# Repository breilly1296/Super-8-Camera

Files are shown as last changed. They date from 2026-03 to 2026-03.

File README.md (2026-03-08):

# Super 8 Camera

**An open-source, self-repairable Super 8 film camera.**

A fully parametric motion picture camera designed from scratch in CadQuery. Every dimension traces back to a single spec file. Every part is manufacturable. 7 field-swappable modules. 10 FDM-printable replacement parts. A complete repair manual generated from the design itself.

## Key Specifications

| Parameter | Value |
|---|---|
| Film format | Kodak Super 8 (5.79 x 4.01 mm frame) |
| Lens mount | C-mount (25.4 mm, 32 TPI, 17.526 mm FFD) |
| Frame rates | 18 fps, 24 fps (switch-selectable) |
| Shutter | 180-degree rotary disc |
| Body envelope | 135 x 80 x 48 mm |
| Body material | Aluminum 6061-T6, 2.5 mm wall |
| Film gate | Brass C360 (free-machining) |
| Drivetrain | Mabuchi FF-130SH, 2-stage Delrin spur gears (6:1) |
| Power | 4x AA alkaline (6.0 V nominal) |
| Weight | ~691 g with batteries |
| BOM cost | $722 (qty 1) / $345 (qty 100) |

## Module Architecture

The camera is organized into 7 field-swappable modules. Each module can be removed and replaced independently without disassembling the rest of the camera.

| Module | Name | Interface | Swap Level | Swap Time | Printable Parts |
|---|---|---|---|---|---|
| MOD-100 | Film Transport | Thumbscrew | Technician | 2 min | Film Channel |
| MOD-200 | Shutter | Thumbscrew | Technician | 90 s | — |
| MOD-300 | Drivetrain | Thumbscrew | Technician | 3 min | Motor Mount, Gearbox Housing, Gears |
| MOD-400 | Cartridge Bay | Snap-fit | User | 30 s | Cartridge Door |
| MOD-500 | Electronics | JST | Technician | 60 s | PCB Bracket |
| MOD-600 | Power | Snap-fit | User | 15 s | Battery Door |
| MOD-700 | Optics | Dovetail | User | 20 s | Viewfinder |

Modules interconnect via 7 JST connectors (XH 2.5 mm + VH 3.96 mm) with unique pin counts to prevent cross-connection. Each connector is keyed to exactly one module pair.

## Framework for Film

This camera borrows its philosophy from [Framework laptops](https://frame.work): **every single part is replaceable, individually purchasable, and forward-compatible across versions.**

### Every Part is Replaceable

There are no glued, riveted, or permanently bonded assemblies. Every component — from the brass film gate to the battery door hinge pin — can be removed with standard hex keys and replaced with an identical spare. The complete [spare parts catalog](super8cam/business/store_catalog.py) lists 35+ SKUs available individually, from a $3 registration pin to complete pre-assembled modules.

### Interface Specification (Frozen)

The [interface standard](super8cam/specs/interface_standard.py) defines the immutable contract between all modules and the chassis:

| Interface | Spec | Status |
|---|---|---|
| Dovetail rail | 60 deg, 4mm top / 6mm base / 3mm deep | FROZEN v1.0 |
| Thumb screws | M3, 20mm center-to-center spacing | FROZEN v1.0 |
| Module slots | 7 slots with exact X/Y/Z coordinates | FROZEN v1.0 |
| Connectors | J1-J7 pinouts, families, wire colors | FROZEN v1.0 |
| Fasteners | M2 / M2.5 / M3 / 1/4"-20 only | FROZEN v1.0 |

A MOD-100 Film Transport manufactured in 2026 will drop into a MOD-100 slot on a chassis built in 2030. The interface spec version guarantees it.

### Future-Proof: Expansion Slot

The chassis includes a reserved expansion slot (MOD-EXP) with a 10-pin JST-XH connector providing:

```
SDA, SCL, TX, RX, PWM1, PWM2, 3V3, 5V, GND, GND
```

V1 ships with a blank cover plate. This enables community-designed expansion modules:
- Digital frame counter
- Bluetooth sync / remote trigger
- Intervalometer (time-lapse)
- Sound recording module
- GPS location logger
- External light meter interface

The expansion slot position, connector pinout, and dovetail mounting are part of the frozen interface standard.

### Module Map

```
  LEFT HALF (chassis)                    RIGHT HALF
  ┌──────────────────────────────┐┌──────────────────────┐
  │  MOD-700   MOD-200           ││  MOD-400             │
  │  Optics    Shutter           ││  Cartridge Bay       │
  │  ┌─────┐  ┌──────┐          ││  ┌──────────────┐    │
  │  │Lens │  │Disc  │          ││  │Receiver      │    │
  │  │Mount│  │Shaft │  MOD-300 ││  │Door          │    │
  │  └─────┘  └──────┘  Drive   ││  └──────────────┘    │
  │                     ┌─────┐ ││                       │
  │  MOD-100            │Motor│ ││  MOD-EXP              │
  │  Film Transport     │Gears│ ││  (Expansion)          │
  │  ┌──────────────┐   └─────┘ ││  ┌───────────┐       │
  │  │Gate+Claw+Cam │           ││  │ 10-pin XH │       │
  │  │Plate+Channel │  MOD-500  ││  │ blank cap │       │
  │  └──────────────┘  ┌──────┐ ││  └───────────┘       │
  │                    │PCB   │ ││                       │
  │                    │J1-J7 │ ││                       │
  │                    └──────┘ ││                       │
  ├─────────────────────────────┤├──────────────────────-┤
  │           MOD-600  Power (Battery Bay)               │
  └──────────────────────────────┘──────────────────────-┘
```

## Design Philosophy

**Specs-driven.** `master_specs.py` defines every dimension, tolerance, material property, and derived constant. Change a wall thickness or gear ratio in one place and the entire camera regenerates to match.

**Manufacturable.** Parts are designed for real processes: 3-axis CNC aluminum, wire EDM for the claw, CNC brass for the film gate, injection-moldable Delrin gears. GD&T callouts follow ASME Y14.5.

**Validated.** The build pipeline runs timing validation, interference detection, thermal analysis, and kinematic simulation. Problems surface at build time, not on the machine shop floor.

**Self-repairable.** Every part has a replacement procedure, tools list, and cost estimate. The generated repair guide PDF walks through symptom diagnosis, module swap, and reassembly verification.

## Interactive Web Explorer

A local web application for browsing the camera design — 3D model viewers, build guide, repair manual, and parts store.

### Quick Start

```bash
cd webapp
npm install
npm run dev
```

Opens at [http://localhost:3000](http://localhost:3000). Features:

- **Home** — Full 3D assembly viewer, key stats, module overview
- **Modules** — 7 field-swappable modules with interactive 3D part viewers
- **Build Guide** — Step-by-step assembly with 3D viewer that updates at each step
- **Repair Guide** — Symptom-based diagnosis with highlighted 3D part views
- **Specs** — All specifications, cam timing diagram, validation results
- **Store** — Complete spare parts catalog (35+ SKUs)
- **About** — Framework for Film philosophy, interface standard, expansion slot docs

To regenerate data from the Python package (optional):

```bash
python webapp/generate_data.py
```

## Build Instructions

### Prerequisites

- Python 3.10+ (3.12 recommended for CadQuery compatibility)
- [Miniforge3](https://github.com/conda-forge/miniforge) (recommended for CadQuery)

### Setup

```bash
# Create conda environment with CadQuery and dependencies
conda create -n super8 python=3.12 cadquery numpy scipy matplotlib reportlab -c conda-forge -y
conda activate super8

# Install the package
cd Super-8-Camera
pip install -e .
```

### Run the Build

```bash
python -m super8cam.build
```

This executes the 7-phase pipeline:

1. **Specifications** — Prints master specs from `master_specs.py`
2. **Validation** — Timing rules, tolerance stack-ups, bearing fits
3. **Analysis** — Kinematics, motor speed check, thermal
4. **Parts Export** — Builds and exports all 27 parts (STEP + STL)
5. **Assemblies Export** — Builds and exports 8 assemblies (STEP)
6. **Interference Detection** — Boolean intersection check on critical pairs
7. **Manufacturing Outputs** — BOM, drawings, checklist, wiring diagram, repair guide

All output goes to `export/`. On Windows, set `PYTHONIOENCODING=utf-8` before running.

### Other Build Modes

```bash
python -m super8cam.build --specs          # print specs summary only
python -m super8cam.build --parts-only     # export parts only
python -m super8cam.build --analysis-only  # run analysis only
python -m super8cam.build --report-only    # generate build report only
```

## Directory Structure

```
Super-8-Camera/
  super8cam/                    Python package
    specs/
      master_specs.py           Single source of truth
      modularity.py             Module architecture + connector map + part catalog
      interface_standard.py     FROZEN interface spec (dovetails, slots, pinouts)
    parts/                      23 CadQuery part modules
    assemblies/                 8 sub-assembly modules
      full_camera.py            Master assembly + interference detection
    analysis/                   Engineering validation
      timing_validation.py      Shutter/claw timing check
      tolerance_stackup.py      Flange distance, registration, bearing fits
      kinematics.py             Claw profiles, motor speed, mechanism validation
      thermal.py                Motor heat, film zone temperature
    manufacturing/              Production outputs
      generate_bom.py           BOM with cost rollup (CSV + PDF)
      generate_drawings.py      Engineering drawing PDFs
      generate_checklist.py     Production checklist PDF
      generate_wiring.py        Wiring harness diagram PDF
      repair_guide.py           Repair & maintenance guide PDF
      generate_qr.py            QR codes + compatibility labels for all parts
    business/                   Store and catalog
      store_catalog.py          Shopify-compatible spare parts catalog (35+ SKUs)
    firmware/                   STM32L031K6 bare-metal firmware
      platformio.ini            PlatformIO build config
      src/
        main.c                  Superloop + HSI16 clock + SysTick
        motor_control.c/h       PID speed control via TIM2 PWM
        metering.c/h            Light meter + galvanometer
        encoder.c/h             Optical encoder input capture
        state_machine.c/h       IDLE/RUN/RAMPDOWN/FAULT state machine
        config.h                Tuning constants
        pinmap.h                Complete pin allocation + connector cross-ref
    build.py                    Master build orchestrator
  export/                       Generated outputs (after build)
  pyproject.toml                Package metadata + dependencies
  verify_fixes.py               25-point mechanical verification suite
```

## Generated Documents

After a full build, the `export/` directory contains:

| File | Description |
|---|---|
| `repair_guide.pdf` | Multi-page repair manual with symptom diagnosis, procedures, and spare parts order form |
| `wiring_diagram.pdf` | Wire harness diagram with connector table and cut list |
| `bom.csv` / `bom.pdf` | Bill of materials with cost rollup at qty 1/25/100 |
| `production_checklist.pdf` | 111-item manufacturing QC checklist |
| `drawings/*.pdf` | Engineering drawings for critical parts |
| `build_report.txt` | Full build report with all analysis results |
| `*.step` / `*.stl` | Part and assembly CAD files |

## Firmware

The camera firmware targets the **STM32L031K6** (ARM Cortex-M0+, 32 KB flash, 8 KB RAM) using bare-metal CMSIS. An Arduino Nano prototype target is also provided.

```bash
cd super8cam/firmware
pip install platformio
pio run -e super8_stm32l0        # build for STM32
pio run -e super8_nano           # build for Arduino Nano
pio run -e super8_stm32l0 -t upload  # flash via ST-Link
```

See `super8cam/firmware/` for the complete firmware source.

## References

- **Kodak Super 8 Film**: Frame size 5.79 x 4.01 mm, perforation pitch 4.234 mm
- **C-Mount Standard**: 25.4 mm diameter, 32 TPI thread, 17.526 mm flange focal distance
- **ASME Y14.5-2018**: Dimensioning and Tolerancing standard
- **ISO 286-1**: System of limits and fits

## License

This project is licensed under the **CERN Open Hardware Licence Version 2 — Strongly Reciprocal (CERN-OHL-S v2)**.

You may redistribute and modify this project and its documentation under the terms of the CERN-OHL-S v2. This licence requires that derivative works are distributed under the same licence terms, ensuring the hardware remains open.

See [https://ohwr.org/cern_ohl_s_v2.txt](https://ohwr.org/cern_ohl_s_v2.txt) for the full licence text.

## Contributing

Contributions are welcome. Please:

1. Fork the repository and create a feature branch
2. Ensure `python verify_fixes.py` passes all 25 checks
3. Run `python -m super8cam.build --specs` to verify imports
4. Submit a pull request with a clear description of your changes

All mechanical dimensions must come from `master_specs.py`. No magic numbers in part files.

## Acknowledgments

- [CadQuery](https://cadquery.readthedocs.io/) — Parametric CAD scripting
- [Kodak](https://www.kodak.com/en/motion/page/super-8-702) — Super 8 film format
- [PlatformIO](https://platformio.org/) — Embedded firmware toolchain
- [ReportLab](https://www.reportlab.com/) — PDF generation

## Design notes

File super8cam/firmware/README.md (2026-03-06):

# Super 8 Camera Firmware

Bare-register CMSIS firmware for the STM32L031K6 controlling all camera
subsystems: motor drive, metering, and operator interface.

## Architecture

```
main.c
 ├── clock_init()       HSI16 at 16 MHz
 ├── systick_init()     1 ms global tick (g_tick_ms)
 ├── uart_init()        USART2 115200 baud debug output
 ├── motor_init()       TIM2 PWM + encoder (TIM21 IC)
 ├── meter_init()       ADC + TIM22 galvo PWM + LEDs
 ├── state_machine_init()
 └── superloop:
      ├── state_machine_update()
      ├── debug_print()         every 500 ms
      └── __WFI()               low-power sleep
```

### Module Dependency

```
config.h  pinmap.h          (constants, no code)
    ↓         ↓
encoder.c/.h                (TIM21 input capture, 4-sample avg)
    ↓
motor_control.c/.h          (TIM2 PWM, PID, ramp, stall)
    ↓
metering.c/.h               (ADC, EV calc, galvo, LEDs)
    ↓
state_machine.c/.h          (8-state FSM, battery, cartridge)
    ↓
main.c                      (init, superloop, UART debug)
```

### State Machine

```
POWER_ON → IDLE → STARTING → RUNNING → STOPPING → IDLE
                                │
                                ├→ STALL → IDLE
                                ├→ CARTRIDGE_EMPTY → IDLE
                                └→ LOW_BATTERY → IDLE
```

| State | Motor | Metering | Entry Condition |
|---|---|---|---|
| POWER_ON | off | off | Boot / reset |
| IDLE | off | preview  | Default state |
| STARTING | ramp-up | active | Trigger pressed |
| RUNNING | PID | active | First encoder pulse |
| STOPPING | ramp-dn | active | Trigger released |
| STALL | killed  | active | No encoder pulse within 200 ms |
| CARTRIDGE_EMPTY | killed  | active | 5 consecutive missed frames |
| LOW_BATTERY | killed  | active | Vbat < 4200 mV |

## Pin Map

| Pin  | Mode | Function |
|---|---|---|
| PA0  | AF2  | TIM2_CH1 — Motor PWM output |
| PA1  | IN | FPS select switch (low=18, high=24) |
| PA2  | IN | Trigger button (active low) |
| PA3  | OUT  | Fault/warning LED |
| PA4  | AF4  | TIM22_CH1 — Galvanometer needle PWM |
| PA5  | OUT  | Green LED (exposure OK) |
| PA6  | OUT  | Red LED (underexposed) |
| PA7  | ANA  | ADC_IN7 — Photodiode / TIA |
| PA9  | AF4  | USART2_TX — Debug UART |
| PA10 | AF4  | USART2_RX — Debug UART |
| PA13 | AF0  | SWDIO (reserved) |
| PA14 | AF0  | SWCLK (reserved) |
| PB0  | IN | DIP bit 0 (ASA select) |
| PB1  | IN | DIP bit 1 (ASA select) |
| PB2  | OUT  | Low-battery LED |
| PB4  | AF6  | TIM21_CH1 — Encoder input capture |
| PB5  | OUT  | Cartridge-empty LED |
| PB6  | IN | Film door switch (optional) |
| PB7  | OUT  | Motor direction (optional) |

## PID Tuning

| Parameter | Value  | Notes |
|---|---|---|
| Kp | 1.8 | Proportional gain |
| Ki | 0.9 | Integral gain |
| Kd | 0.05 | Derivative gain |
| Update interval  | 20 ms  | 50 Hz PID rate |
| Anti-windup | ±400 | Integral clamp (duty units) |
| D filter alpha | 0.3 | Low-pass on derivative term |
| Rate limit | ±50 | Max duty change per PID cycle |

## Build & Flash

### Prerequisites

- [PlatformIO CLI](https://platformio.org/install/cli) or VS Code extension
- ST-Link V2 programmer (built into Nucleo board)

### Commands

```bash
# Build for STM32L031K6 (production)
pio run -e super8_stm32l0

# Flash via ST-Link
pio run -e super8_stm32l0 -t upload

# Monitor debug UART (115200 baud)
pio device monitor -b 115200

# Build for Arduino Nano (prototype)
pio run -e super8_nano

# Flash Nano via USB
pio run -e super8_nano -t upload
```

### Debug Output Format

At 500 ms intervals on USART2 (115200, 8N1):

```
STATE    FPS_TGT  FPS_ACT  DUTY  EV    f/STOP  ASA  VBAT     FRAMES
RUNNING  24       23.8     487   12.3  f/8.0   100  5840mV   142
```

## Calibration

### Light Meter

1. Set DIP to ASA 100 (01), FPS to 24
2. Point camera at an 18% grey card under known illumination
3. Note the UART `EV` output
4. Adjust the `cal_table[]` entries in `metering.c` to match your
   reference meter readings
5. Repeat at multiple light levels (EV 4 through EV 14)

### Motor PID

1. Flash firmware, connect UART
2. Set FPS switch to 18, press trigger
3. Watch `FPS_ACT` column for oscillation:
   - Oscillating → reduce Kp
   - Sluggish response → increase Kp
   - Steady-state error → increase Ki
   - Overshoot on start → increase Kd or reduce Kp
4. Repeat at 24 fps

### Battery Threshold

The default `VBAT_LOW_THRESHOLD_MV = 4200` corresponds to 4×1.05V per
cell (alkaline end-of-life).  For NiMH cells (1.0V cutoff), lower to
4000 mV.  Edit in `config.h`.

## Hardware Notes

- **Motor driver**: N-channel MOSFET (IRLML6344) driven by PWM on PA0.
  Gate driven directly from GPIO (3.3V logic level compatible).
- **Encoder**: Slotted optical switch (e.g., GP1A57HRJ00F) with 3.3V
  pull-up on output.  One slot per revolution = one pulse per frame.
- **Photodiode**: BPW34 with 1 MΩ TIA (OPA340).  Output 0–3.3V maps
  to approximately EV 1–17.
- **Galvanometer**: Moving-coil meter driven by filtered PWM.  Add a
  10 kΩ series resistor and 10 µF cap for smoothing.

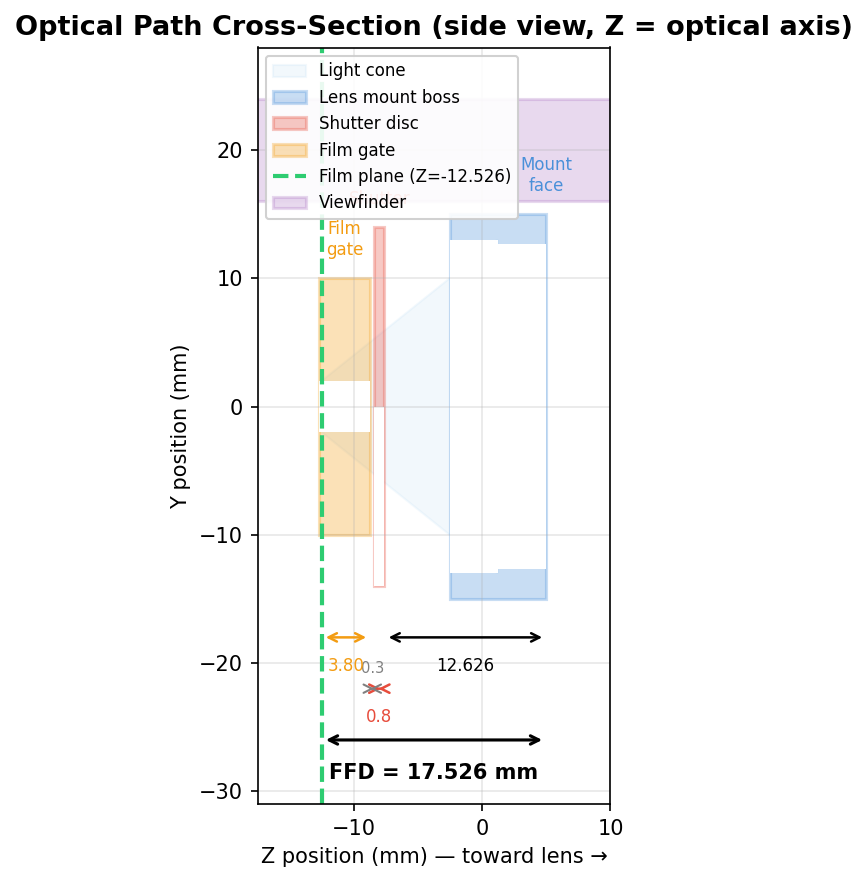
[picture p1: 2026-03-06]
optical_path_cross_section.png

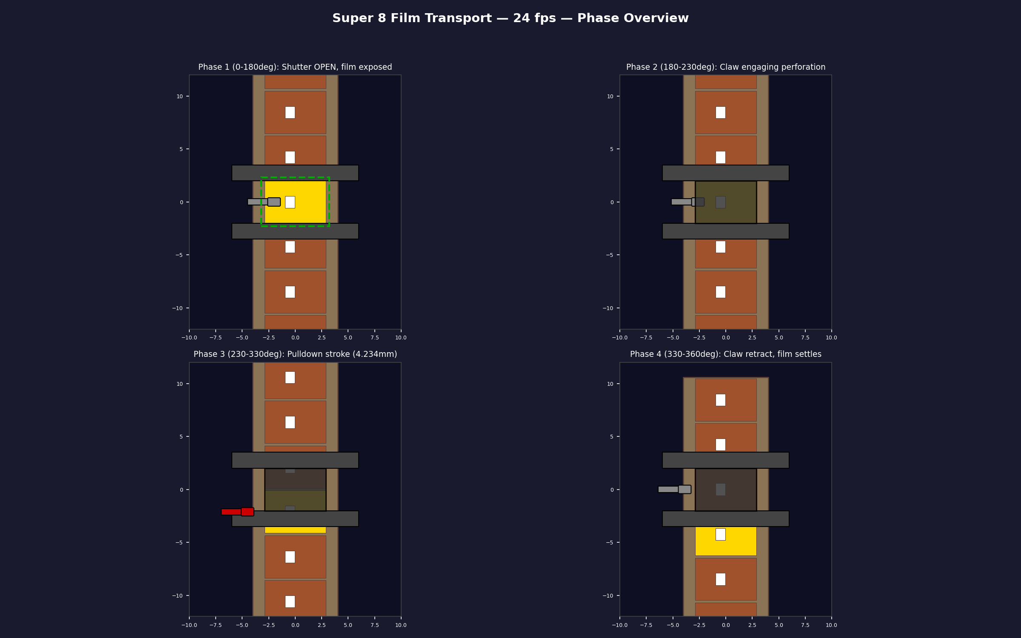
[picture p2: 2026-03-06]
transport_24fps_preview.png

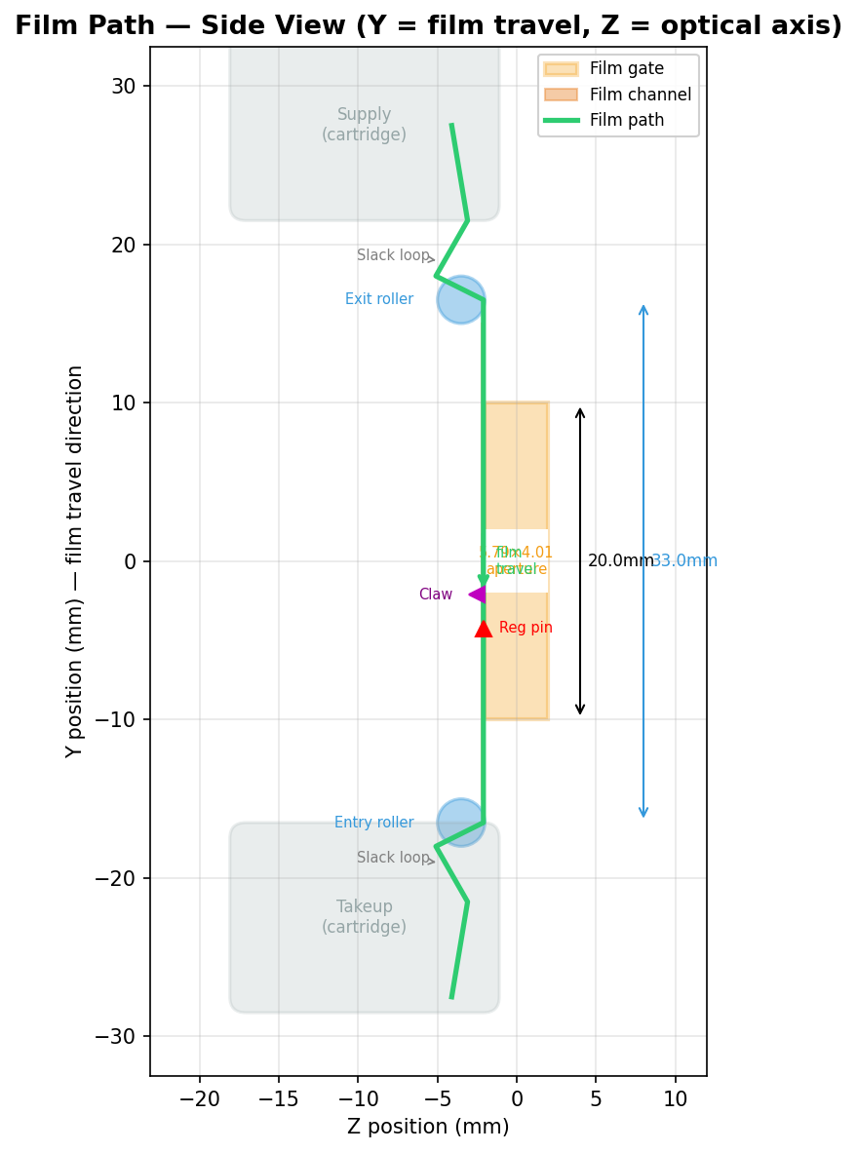
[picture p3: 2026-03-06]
film_path_diagram.png

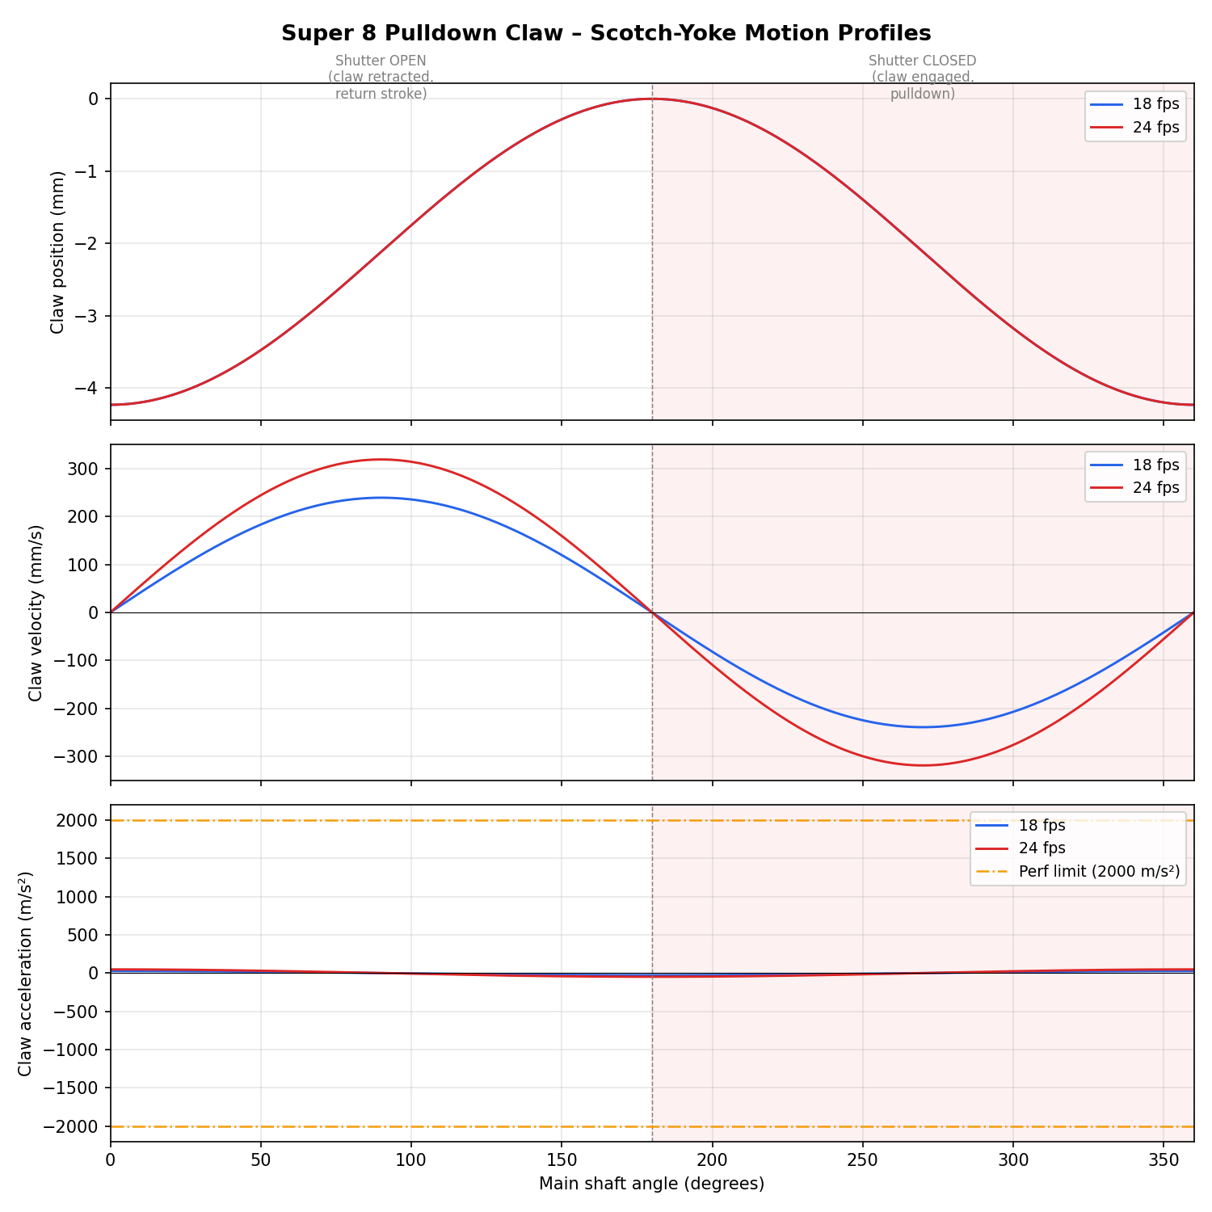
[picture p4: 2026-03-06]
super8_claw_plots.png

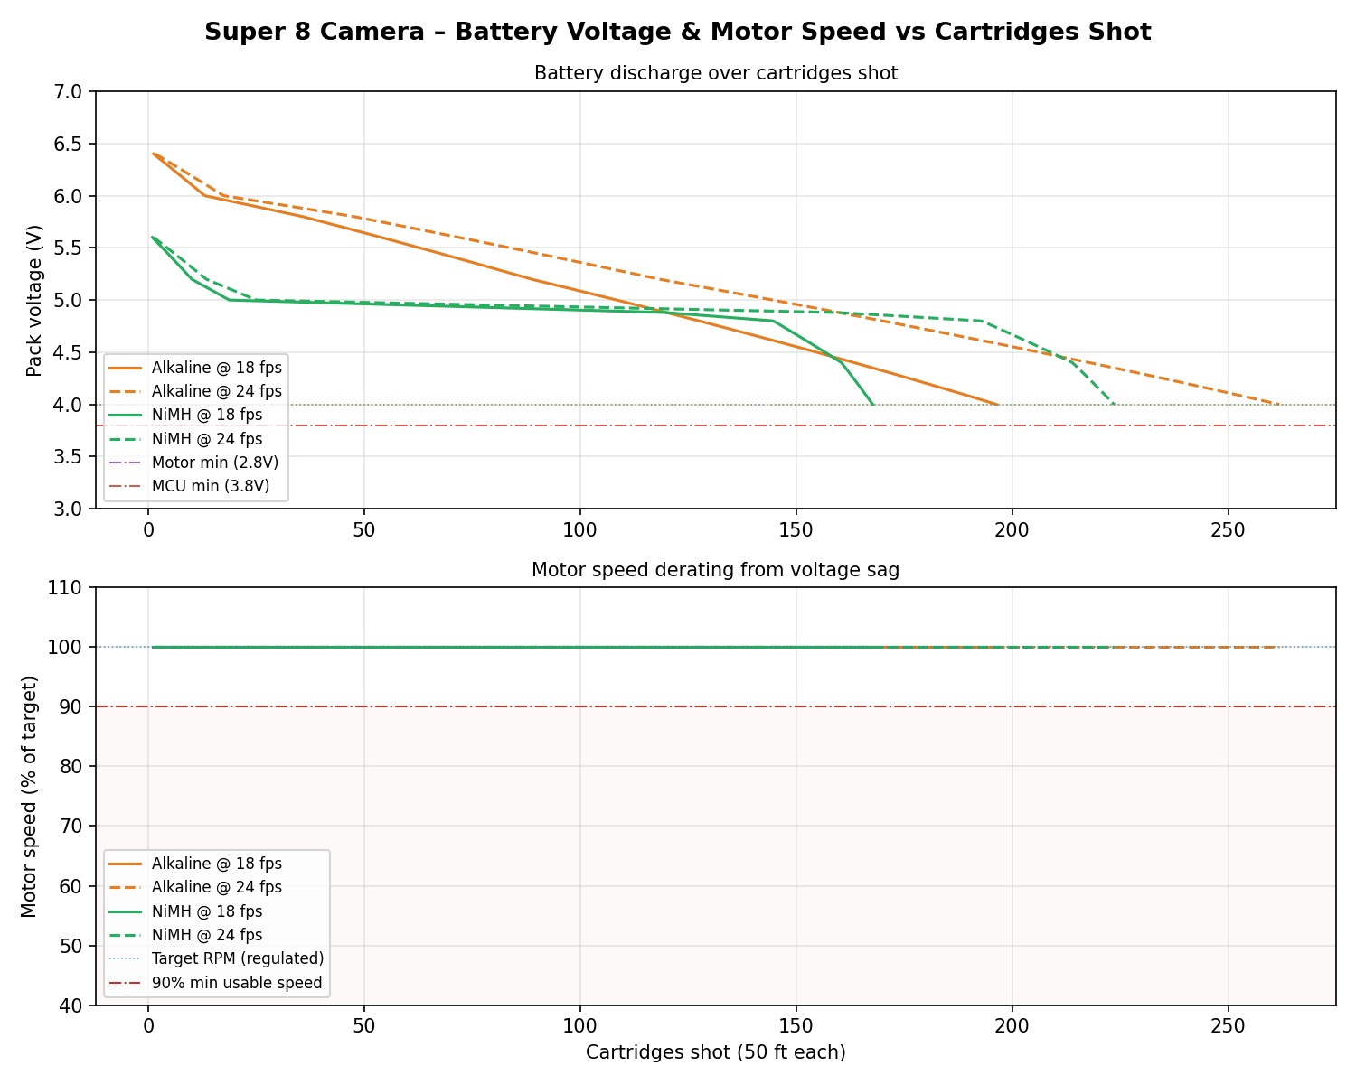
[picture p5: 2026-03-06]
super8_battery_life.png

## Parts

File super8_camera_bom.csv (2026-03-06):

Reference | Value | Footprint | MPN | Description | Qty
U1 | STM32L031K6T6 | LQFP-32_7x7mm_P0.8mm | STM32L031K6T6 | ARM Cortex-M0+ MCU 32KB Flash | 1
U2 | DRV8837 | WSON-8_2x2mm_P0.5mm | DRV8837DSGR | 1.8A H-bridge motor driver | 1
U3 | MCP6001 | SOT-23-5 | MCP6001T-I/OT | 1 MHz rail-to-rail op-amp | 1
U4 | AMS1117-5.0 | SOT-223-3 | AMS1117-5.0 | 5V 1A LDO regulator | 1
U5 | AMS1117-3.3 | SOT-223-3 | AMS1117-3.3 | 3.3V 1A LDO regulator | 1
Q1 | SI2301 | SOT-23 | SI2301CDS-T1-GE3 | P-channel MOSFET -20V -2.3A | 1
F1 | 500mA | Fuse_1206 | MF-MSMF050-2 | 500mA resettable PTC fuse | 1
D1 | BPW34 | BPW34_DIL | BPW34 | Silicon PIN photodiode | 1
R1 | 1M | R_0603 |  | TIA feedback resistor 1 MOhm | 1
C1 | 10pF | C_0603 |  | TIA feedback cap (bandwidth limit) | 1
C10 | 100nF | C_0603 |  | Bypass cap U1 VDD | 1
C11 | 100nF | C_0603 |  | Bypass cap U1 VDDA | 1
C12 | 100nF | C_0603 |  | Bypass cap U2 VCC | 1
C13 | 100nF | C_0603 |  | Bypass cap U3 VDD | 1
C14 | 100nF | C_0603 |  | Bypass cap U4 output | 1
C15 | 100nF | C_0603 |  | Bypass cap U5 output | 1
C20 | 10uF | C_0805 |  | Bulk cap VIN rail | 1
C21 | 10uF | C_0805 |  | Bulk cap 5V rail | 1
C22 | 10uF | C_0805 |  | Bulk cap 3V3 rail | 1
C23 | 10uF | C_0805 |  | AMS1117-5.0 input cap | 1
C24 | 10uF | C_0805 |  | AMS1117-3.3 input cap | 1
R2 | 10K | R_0603 |  | Trigger pull-up to 3V3 | 1
R3 | 10K | R_0603 |  | NRST pull-up to 3V3 | 1
R4 | 330 | R_0603 |  | Warning LED resistor | 1
R5 | 330 | R_0603 |  | Green LED resistor | 1
R6 | 330 | R_0603 |  | Red LED resistor | 1
R7 | 330 | R_0603 |  | Low-bat LED resistor | 1
R8 | 330 | R_0603 |  | Cart-empty LED resistor | 1
D2 | LED_Red | LED_0603 |  | Fault/warning LED | 1
D3 | LED_Green | LED_0603 |  | Exposure OK LED | 1
D4 | LED_Red | LED_0603 |  | Exposure under LED | 1
D5 | LED_Yellow | LED_0603 |  | Low battery LED | 1
D6 | LED_Red | LED_0603 |  | Cartridge empty LED | 1
J1 | JST_PH_4pin | JST_PH_B4B-PH-K_1x04_P2.00mm_Vertical | B4B-PH-K-S | Motor connector (A, B, ENC, GND) | 1
J2 | JST_PH_2pin | JST_PH_B2B-PH-K_1x02_P2.00mm_Vertical | B2B-PH-K-S | Battery input connector | 1
J3 | ISP_6pin | PinHeader_2x03_P2.54mm_Vertical |  | SWD programming header | 1
SW1 | Trigger | SW_Push_SPST |  | Trigger button SPST | 1
SW2 | FPS_Toggle | SW_Toggle_SPDT |  | 18/24 FPS toggle switch | 1
SW3 | DIP_2pos | DIP-02_SMD |  | ASA select 2-bit DIP switch | 1

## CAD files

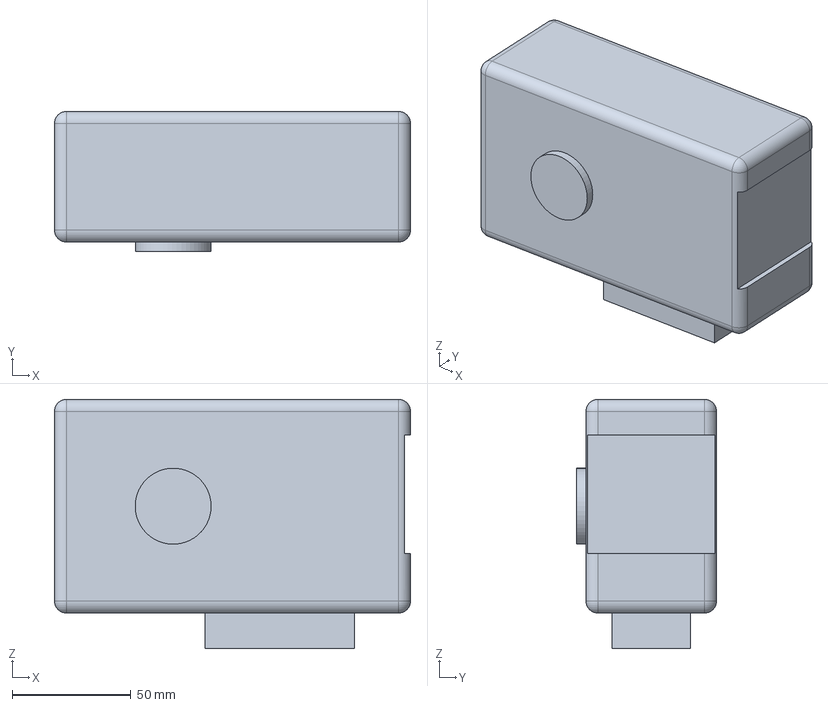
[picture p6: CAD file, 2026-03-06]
camera_body.step
150.0 x 59.0 x 105.0 mm

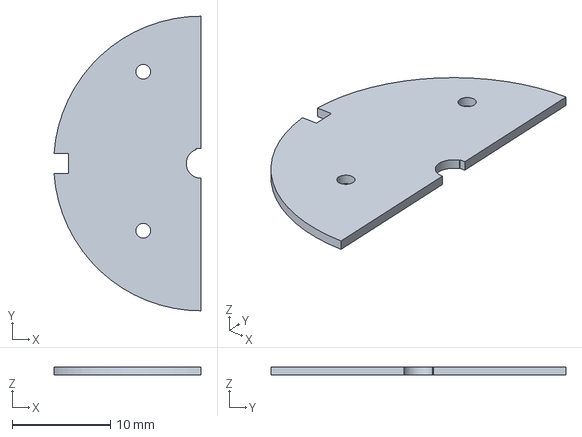
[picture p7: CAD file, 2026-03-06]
shutter_disc.step
15.0 x 30.0 x 0.8 mm

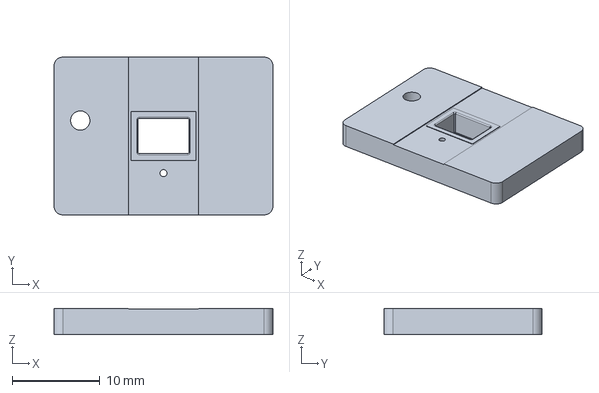
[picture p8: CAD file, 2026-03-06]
film_gate.step
25.0 x 18.0 x 3.00 mm

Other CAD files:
camera_body.stl
film_gate.stl
shutter_disc.stl

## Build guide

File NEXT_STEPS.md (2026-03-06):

# Next Steps: From Digital Files to Physical Camera

This document outlines the 12-step path from the current parametric CAD model to a working Super 8 camera shooting real film.

---

## Step 1: Import into Fusion 360 and Review

**Import `export/full_camera.step` into Fusion 360.**

- Check all 48 solids imported cleanly (no missing faces, degenerate geometry)
- Verify part-to-part interfaces: screw boss alignment, bearing pocket depths, shaft fits
- Run Fusion 360's native interference analysis to cross-check against our build report
- Review the 9 flagged interferences and adjust datum offsets in assembly positioning
- Section-view the film path end-to-end: cartridge receiver through gate to take-up

**Key fixes needed before prototyping:**
- Resolve shutter-vs-gate interference (64 mm^3 overlap) — likely need 0.5 mm axial offset
- Resolve cam-vs-gate interference (487 mm^3) — cam housing needs clearance pocket
- Adjust motor mount and PCB bracket positions to clear body shell interior
- Fix viewfinder-vs-top-plate overlap (27 mm^3) — lower viewfinder tube or add top plate cutout

**Deliverable:** Annotated Fusion 360 project file with all interferences resolved.

---

## Step 2: 3D Print Fit-Check Prototypes

**Print the body shells, film gate, and cartridge receiver in PLA or PETG.**

- Use the STL files in `export/` directly — they're already watertight meshes
- Print at 0.2 mm layer height for dimensional accuracy
- Key fit checks:
  - Does a real Super 8 cartridge seat and latch in the receiver?
  - Does the film channel guide the film strip without binding?
  - Does the C-mount thread adapter screw in and bottom out at correct flange distance?
  - Do the body halves mate flush with the M2.5 screw pattern aligned?
  - Is there enough finger clearance on the trigger?
- Measure critical dimensions with calipers and compare to specs

**Deliverable:** Fit-check report with photos and measurements. List of geometry corrections.

---

## Step 3: CNC the Brass Film Gate

**This is the highest-precision part. Machine it first to validate the process.**

- Material: Brass C360 (free-machining, excellent dimensional stability)
- Send `export/film_gate.step` plus `export/drawings/film_gate.pdf` to CNC shop
- Critical dimensions:
  - Aperture: 5.79 x 4.01 mm +/- 0.005 mm
  - Registration pin hole: 0.813 +0.000/-0.005 mm
  - Claw slot: 1.5 x 3.0 mm with 0.1 mm radii
  - Surface finish: Ra 0.4 um on film-contact surfaces
- Request first-article inspection report with CMM data

**Deliverable:** Inspected brass film gate with FAI report.

---

## Step 4: Machine the Claw and Registration Pin

**Wire EDM or Swiss-turn the claw mechanism from AISI 4140 steel.**

- Claw tip must match perforation geometry: 1.143 x 0.914 mm engagement
- Pulldown stroke: exactly 4.234 mm (one perf pitch)
- Registration pin: 0.813 mm diameter, ground finish
- Heat treat to Rc 45-50 for wear resistance
- These parts mate with the brass gate — verify fit together before assembly

**Deliverable:** Functional claw + pin set, verified against gate.

---

## Step 5: Machine the Cam, Shaft, and Gears

**The drivetrain defines film-advance timing.**

- Main shaft: AISI 4140, 6 sections, 4mm bearing journals (k6 tolerance for press fit)
- Pulldown cam: AISI 4140 face cam with modified trapezoidal profile — CNC 4-axis or wire EDM the cam track
- Gears: Delrin 150 (acetal). Module 0.5 and 0.8 spur gears can be CNC'd or hobbed
  - Stage 1: 10T pinion / 50T gear (5:1)
  - Stage 2: 12T pinion / 36T gear (3:1)
  - Total ratio: 15:1 (NOTE: may need reducing to ~6:1 per motor speed analysis)
- Order 694ZZ and 683ZZ bearings (standard sizes, available from any bearing supplier)

**Deliverable:** Complete drivetrain subassembly, manually rotatable to verify cam motion.

---

## Step 6: CNC the Body Shells

**Machine left and right body halves from 6061-T6 billet.**

- Wall thickness: 2.5 mm throughout
- Internal pockets for motor mount, PCB, battery holder
- M2.5 threaded bosses for shell assembly (12 screws)
- 1/4-20 Helicoil insert pocket on bottom plate (tripod mount)
- Hard anodize after machining (Type III, 0.025 mm buildup — account for in tolerances)
- Also machine: top plate, bottom plate, battery door, cartridge door

**Deliverable:** Anodized body shell set. All doors open/close. Battery compartment fits 4x AA.

---

## Step 7: Build the Control PCB

**The firmware is written but the PCB needs layout.**

- Schematic is specified in `master_specs.py` (PCB dataclass) but not yet captured in KiCad
- Key components:
  - STM32L031K6 (LQFP-32)
  - GP1A57HRJ00F optical encoder
  - IRLML6344 motor MOSFET
  - BPW34 photodiode (light meter)
  - 100 uA galvanometer meter movement
  - 2-position DIP switch (film speed)
  - FPS toggle switch
- Board outline: 40 x 25 mm, 4-layer FR4 with ENIG finish
- Flash the firmware using ST-Link V2 and PlatformIO

**Deliverable:** Assembled and flashed PCB. Motor spins, encoder reads, meter needle deflects.

---

## Step 8: Prototype Assembly

**Assemble all subsystems into the body for the first time.**

- Follow the 111-item production checklist (`export/production_checklist.pdf`)
- Assembly order:
  1. Press bearings into gearbox housing and body shell bearing pockets
  2. Install main shaft with gears into gearbox
  3. Mount motor to motor bracket, mesh pinion with stage 1 gear
  4. Install claw mechanism and registration pin in film gate
  5. Mount film gate to left body shell
  6. Install shutter disc on shaft
  7. Mount PCB and connect wiring harness
  8. Install cartridge receiver in right body shell
  9. Join body halves
  10. Install top plate, bottom plate, doors
  11. Thread C-mount lens adapter

**Deliverable:** Fully assembled prototype camera. Holds together. Mechanism turns by hand.

---

## Step 9: Bench Test the Mechanism

**Power up and validate without film.**

- Connect 4x AA batteries
- Toggle to 18 fps, press trigger — verify motor starts and stabilizes
- Measure shaft speed with optical tachometer (target: 1080 RPM at shaft = 18 fps)
- Toggle to 24 fps — verify 1440 RPM
- Check PID settling time (spec: < 200 ms to +/- 1%)
- Listen for gear noise, vibration, binding
- Verify shutter clears gate at all rotation angles (strobe test)
- Check claw engagement/retraction through gate slot
- Measure current draw (spec: ~270 mA at 24 fps)

**Deliverable:** Bench test report with speed, current, and vibration data.

---

## Step 10: Shoot the First Roll of Film

**Load a Kodak Super 8 cartridge and expose 50 feet of film.**

- Use a well-lit outdoor scene (ISO 200 Kodak Vision3 200T or 500T)
- Verify:
  - Cartridge seats and latches correctly
  - Film feeds smoothly through gate
  - Claw engages perforations without tearing
  - Registration pin stabilizes frame during exposure
  - Shutter timing gives correct exposure (meter needle at center)
  - Camera runs at constant speed for full 50 ft (about 2.5 min at 24 fps)
- Send exposed cartridge to a film lab for processing and scanning
  - Recommended: Kodak Film Lab Atlanta, Pro8mm, or Spectra Film & Video
- Review scanned footage for:
  - Frame steadiness (registration accuracy)
  - Exposure consistency
  - Edge sharpness (flange distance correctness)
  - Scratches or emulsion damage (pressure plate / gate finish issues)

**Deliverable:** Processed and scanned first roll. Frame grabs showing registration quality.

---

## Step 11: Iterate on Findings

**Fix whatever the first roll reveals.**

Common issues and likely fixes:
- **Unsteady frames**: Tighten registration pin tolerance, add pin pre-load spring
- **Exposure variation**: Tune PID gains for more stable speed, check shutter balance
- **Soft focus**: Shim lens mount to adjust flange distance (the stack-up analysis flagged this)
- **Film scratches**: Re-lap film gate surfaces to Ra 0.2 um, check pressure plate force
- **Torn perforations**: Reduce claw engagement force, verify pulldown cam profile
- **Motor stalling**: Reduce gear ratio from 15:1 to ~6:1, or switch to higher-torque motor
- **Overheating**: Add thermal break between motor mount and gate (the analysis showed 3.8 C rise — manageable, but margin is thin at 24 fps continuous)

**Deliverable:** Rev 2 parts list and updated STEP files.

---

## Step 12: Document and Share

**Prepare for community release or crowdfunding.**

- Create render images and assembly animation (Fusion 360 or Blender)
- Write detailed assembly guide with photos from Step 8
- Document the BOM with supplier links and lead times
- Create a KiCad project with schematic, PCB layout, and Gerber files
- Record a demo video with footage shot on the camera
- Publish to GitHub with CERN-OHL-S v2 license
- Consider a Crowd Supply or Kickstarter campaign if there's interest
  - Qty 25 cost: $467/camera
  - Qty 100 cost: $345/camera
  - Realistic retail price with margin: $599-799

**Deliverable:** Public repository, demo video, and (optionally) a crowdfunding campaign page.

---

## Summary Timeline (Estimated)

| Step | Duration | Depends On |
|---|---|---|
| 1. Fusion 360 review | 1-2 weeks | -- |
| 2. 3D print fit check | 1 week | Step 1 |
| 3. CNC brass gate | 2-3 weeks | Step 1 |
| 4. Claw + reg pin | 2-3 weeks | Step 3 |
| 5. Drivetrain | 2-3 weeks | Step 1 |
| 6. Body shells | 3-4 weeks | Step 2 |
| 7. Control PCB | 3-4 weeks | Step 1 |
| 8. Assembly | 1 week | Steps 3-7 |
| 9. Bench test | 1 week | Step 8 |
| 10. First roll | 1-2 weeks | Step 9 |
| 11. Iteration | 2-4 weeks | Step 10 |
| 12. Documentation | 2-3 weeks | Step 11 |

**Critical path: ~16-20 weeks from design freeze to first footage.**

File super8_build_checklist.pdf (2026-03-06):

# SUPER 8 CAMERA

### Production Build Checklist

Serial Number: | ________________ | Date: | ________________
Technician: | ________________ | Initials: | ________
Firmware Ver: | ________________ | Work Order: | ________________

## 1. INCOMING INSPECTION

Verify each component against acceptance criteria before starting assembly. Reject or quarantine any part that fails.

[ ] | Ref | Part Description | Acceptance Criteria | OK
[ ] | U1 | STM32L031K6T6 LQFP-32 | Correct marking, no bent pins, verify date code | [ ]
[ ] | U2 | DRV8837 WSON-8 | Marking matches MPN, pad exposure visible | [ ]
[ ] | U3 | MCP6001 SOT-23-5 | Correct orientation dot, no damaged leads | [ ]
[ ] | U4 | AMS1117-5.0 SOT-223 | Verify 5.0 marking (not 3.3) | [ ]
[ ] | U5 | AMS1117-3.3 SOT-223 | Verify 3.3 marking (not 5.0) | [ ]
[ ] | Q1 | SI2301 P-FET SOT-23 | Verify P-channel marking, correct pinout | [ ]
[ ] | F1 | 500mA Polyfuse 1206 | Verify 500mA rating marking | [ ]
[ ] | D1 | BPW34 Photodiode | Glass window clean, no cracks, leads intact | [ ]
[ ] | D2-D6 | LEDs (R/G/Y) 0603 | Correct colour per ref, verify with test current | [ ]
[ ] | R1 | 1M 0603 1% | Verify value with DMM: 1.00M +/-1% | [ ]
[ ] | R2-R3 | 10K 0603 5% | Verify value with DMM: 10K +/-5% | [ ]
[ ] | R4-R8 | 330R 0603 5% | Verify value with DMM: 330 +/-5% | [ ]
[ ] | C1 | 10pF C0G 0603 | Marking/bag label matches value | [ ]
[ ] | C10-C15 | 100nF X7R 0603 (x6) | Marking/bag matches, qty=6 | [ ]
[ ] | C20-C24 | 10uF X5R 0805 (x5) | Marking/bag matches, qty=5 | [ ]
[ ] | J1 | JST-PH 4-pin vertical | 4 pins, no bent contacts, latch intact | [ ]
[ ] | J2 | JST-PH 2-pin vertical | 2 pins, latch intact | [ ]
[ ] | J3 | 2x3 pin header 2.54mm | Straight pins, correct pitch | [ ]
[ ] | SW1 | Trigger push-button | Tactile click, <100 ohm closed, >1M open | [ ]
[ ] | SW2 | SPDT toggle switch | Firm detent both positions, wipe resistance <50m | [ ]
[ ] | SW3 | 2-pos DIP switch SMD | Both positions click, contact resistance <100m | [ ]
[ ] | -- | Film gate (machined) | Aperture 5.79+/-0.02 x 4.01+/-0.02mm, no burrs, channel 0.1mm deep | [ ]
[ ] | -- | Shutter disc (stamped) | OD 30.0+/-0.1mm, shaft hole 3.0+0.02/-0mm, balance holes present | [ ]
[ ] | -- | DC motor + gearbox | Shaft spins freely, no grinding, 6V nom. | [ ]
[ ] | -- | Camera body shell | No warping, all cutouts present, M2 bosses intact | [ ]
[ ] | -- | C-mount lens assembly | Threads clean, focus smooth, rear element clean | [ ]
[ ] | -- | Super 8 cartridge door | Hinge pin fit, latch engages, light-tight | [ ]
[ ] | -- | Optical encoder disc+sensor | Slot aligned, sensor responds to interruption | [ ]
[ ] | -- | PCB (bare, from fab) | No shorts (visual), via fill OK, silkscreen legible | [ ]

[ ] | Ref | Part Description | Acceptance Criteria | OK
[ ] | -- | Fasteners kit | M2x5 (x8), M2x8 (x4), M2 nuts (x12), M2 washers (x12) | [ ]
[ ] | -- | 4xAA battery holder | Spring contacts intact, polarity marked, lead length OK | [ ]

Incoming inspection complete: _______ (initials) Date: _________

## 2. SUB-ASSEMBLY: FILM GATE

[ ] | Step | Procedure
[ ] | FG-1 | Clean gate plate with IPA and lint-free wipe
[ ] | FG-2 | Inspect aperture under 10x loupe — no scratches or burrs on film-side lip
[ ] | FG-3 | Verify registration pin hole: insert 0.80mm gauge pin — must pass freely
[ ] | FG-4 | Verify channel depth with depth gauge: 0.10 +/- 0.02mm
[ ] | FG-5 | Install pressure plate springs (2x) — verify even tension by feel
[ ] | FG-6 | Function check: slide test film strip through channel — must glide without catching

## 3. SUB-ASSEMBLY: SHUTTER DISC

[ ] | Step | Procedure
[ ] | SH-1 | Press keyway shaft coupling onto motor shaft — align keyway, firm press fit
[ ] | SH-2 | Mount shutter disc on coupling — verify keyway engagement, no play
[ ] | SH-3 | Spin by hand — disc must rotate freely with no wobble (< 0.1mm runout)
[ ] | SH-4 | Verify optical sensor flag notch clears the sensor body with > 0.5mm gap
[ ] | SH-5 | Connect motor to bench supply at 6V — verify smooth rotation both directions
[ ] | SH-6 | Measure balance: hold shaft horizontal — disc should not settle to one position

## 4. SUB-ASSEMBLY: MOTOR + GEARBOX + ENCODER

[ ] | Step | Procedure
[ ] | MT-1 | Install motor into body shell pocket — secure with 2x M2x8 screws
[ ] | MT-2 | Torque motor screws to 0.15 N-m (finger-tight + 1/8 turn)
[ ] | MT-3 | Route motor leads through body channel — verify no pinch points
[ ] | MT-4 | Install encoder disc on secondary shaft — verify slot aligns with sensor
[ ] | MT-5 | Mount optical encoder sensor bracket — adjust gap to 1.0 +/- 0.3mm
[ ] | MT-6 | Connect motor leads to J1 pigtail — verify polarity (red=A, black=B)
[ ] | MT-7 | Spin shaft by hand — encoder sensor output toggles (verify with scope or LED)

## 5. SUB-ASSEMBLY: PCB STUFFING + TEST

[ ] | Step | Procedure
[ ] | PCB-1 | Apply solder paste to PCB using stencil — inspect for bridging under 10x loupe
[ ] | PCB-2 | Place all SMD components per pick-and-place coordinates
[ ] | PCB-3 | Reflow solder — standard lead-free profile (peak 245C, 60-90s above liquidus)
[ ] | PCB-4 | Post-reflow inspection: check all joints under 10x — rework any cold joints
[ ] | PCB-5 | Solder through-hole: J1, J2, J3 connectors — verify flush seating
[ ] | PCB-6 | Clean flux residue with IPA
[ ] | PCB-7 | Continuity check: 3V3 to GND > 1K ohm (no short), 5V to GND > 1K ohm
[ ] | PCB-8 | Power-on test: connect 6V bench supply to J2 — verify 5.0V +/-0.1V on 5V rail

[ ] | Step | Procedure
[ ] | PCB-9 | Verify 3.3V +/-0.1V on 3V3 rail
[ ] | PCB-10 | Flash firmware via J3 (SWD) — verify successful program/verify cycle
[ ] | PCB-11 | Post-flash: MCU heartbeat LED blinks (if debug LED populated)

Sub-assemblies complete: _______ (initials) Date: _________

## 6. FINAL ASSEMBLY

Complete steps in order. Do not skip ahead. Record torque values where specified.

[ ] | Step | Procedure | Verification
[ ] | FA-1 | Install PCB on standoff posts inside body — 4x M2x5 screws, torque 0.10 N-m | Verify PCB clears all internal features
[ ] | FA-2 | Connect motor JST cable to J1 | Verify latch clicks
[ ] | FA-3 | Connect battery holder leads to J2 | Red=pin 1 (VIN), Black=pin 2 (GND)
[ ] | FA-4 | Route all wires in body channels — secure with adhesive clips | No wires cross moving parts
[ ] | FA-5 | Install film gate sub-assembly — 2x M2x5 screws, torque 0.10 N-m | Aperture centered in body window
[ ] | FA-6 | Align film gate: insert alignment gauge through gate and lens opening | Gate must be perpendicular to optical axis within 0.5 deg
[ ] | FA-7 | Install shutter sub-assembly — verify disc clears gate by > 0.3mm | Spin check: no contact with gate or body
[ ] | FA-8 | Set C-mount flange distance: 17.526mm from sensor plane to mount face | Use flange distance gauge or calibrated spacer
[ ] | FA-9 | Install C-mount lens ring — thread in, verify firm stop | Test-fit a lens: focus reaches infinity
[ ] | FA-10 | Install trigger button and FPS toggle switch in body cutouts | Verify actuation feel and detent
[ ] | FA-11 | Install DIP switch (ASA select) in body recess | All 4 positions readable by firmware
[ ] | FA-12 | Install LEDs in body light pipes / windows | Verify visibility from outside: power on, cycle all LEDs
[ ] | FA-13 | Install cartridge door — hinge pin, latch mechanism | Door opens > 90 deg, latches firmly closed
[ ] | FA-14 | Install battery compartment door on bottom | Verify spring contacts engage battery holder
[ ] | FA-15 | Install tripod mount insert (1/4-20) — thread in with Loctite 242 | Torque to 0.5 N-m, verify thread engagement > 5mm
[ ] | FA-16 | Final exterior inspection: all screws flush, no gaps > 0.2mm, cosmetic check | Label serial number on inside of battery door

Final assembly complete: _______ (initials) Date: _________

## 7. CALIBRATION: METERING SYSTEM

Requires: calibrated light source, reference light meter, serial debug connection.

[ ] | Step | Procedure
[ ] | CM-1 | Set up calibration light source: integrating sphere or uniform diffuser at EV 10
[ ] | CM-2 | Set DIP to ASA 100, FPS to 18
[ ] | CM-3 | Read ADC value at EV 10 — record: _______ mV (expected ~950 mV)
[ ] | CM-4 | Adjust calibration table entry for EV 10 if off by > 50mV
[ ] | CM-5 | Repeat at EV 6 (dim) and EV 14 (bright) — record values
[ ] | CM-6 | Verify galvanometer needle: at EV 12 / ASA 100 / 18fps, needle should read ~f/5.6
[ ] | CM-7 | Verify green LED on at EV 12, red LED on at EV 4 (underexposed)
[ ] | CM-8 | Cycle through all 4 ASA settings — needle must respond correctly

## 8. CALIBRATION: MOTOR SPEED

Requires: dummy film cartridge or encoder test jig, strobe/oscilloscope.

[ ] | Step | Procedure
[ ] | CMS-1 | Load dummy film cartridge (or use encoder-only test mode)
[ ] | CMS-2 | Set FPS switch to 18 — press trigger
[ ] | CMS-3 | Wait for PID to settle (2 seconds) — measure fps with strobe or scope
[ ] | CMS-4 | Record: measured fps = _______ (accept: 18.0 +/- 0.5 fps)
[ ] | CMS-5 | Switch FPS to 24 during run — verify smooth transition
[ ] | CMS-6 | Record: measured fps = _______ (accept: 24.0 +/- 0.5 fps)
[ ] | CMS-7 | Release trigger — verify soft stop (no abrupt halt)
[ ] | CMS-8 | Stall test: hold shutter disc — motor must shut off within 200ms, LED blinks

Calibration complete: _______ (initials) Date: _________

## 9. QUALITY CONTROL TESTS

All tests must pass before the unit ships. Record results in the Result column.

[ ] | Test ID | Test Name | Procedure | Result
[ ] | QC-1 | Film advance test | Load dummy cartridge, run 50 frames at 18fps. Count encoder pulses: must be 50 +/- 1. Inspect film — no scratches, perforations intact. | PASS / FAIL
[ ] | QC-2 | Film advance test (24fps) | Run 50 frames at 24fps. Verify count and film condition. | PASS / FAIL
[ ] | QC-3 | Light leak check | Load unexposed test film, close cartridge door, expose body to bright light (60W lamp at 15cm) for 60 seconds. Develop film — no fogging on any frame. | PASS / FAIL
[ ] | QC-4 | Shutter timing verification | Use phototransistor + oscilloscope at gate aperture. Measure open/closed duty cycle at 18fps: expect 50% +/- 3%. Repeat at 24fps. | 18fps: ____% | 24fps: ____%
[ ] | QC-5 | Metering accuracy spot check | Compare needle reading to reference meter at EV 8, 10, 12 (ASA 100). Must agree within +/- 0.5 EV. | EV8: +/-___ | EV10: +/-___ | EV12: +/-___
[ ] | QC-6 | Battery life spot check | Insert fresh 4xAA alkaline. Run motor at 24fps continuously. Record time until low-battery LED lights. Minimum acceptable: 30 minutes. | Time: ___ min
[ ] | QC-7 | Cartridge-end detection | With motor running, simulate cartridge end (block encoder). Camera must stop motor and blink warning within 5 missed frames. | PASS / FAIL
[ ] | QC-8 | Drop / shock test (optional) | 10cm drop onto padded surface, 3 axes. Verify all functions still work. No loose parts rattling. | PASS / FAIL / SKIP

## 10. FINAL SIGN-OFF

| Name (print) | Signature | Date
Built by: | ________________ | ________________ | __________
QC inspected by: | ________________ | ________________ | __________
Approved for ship: | ________________ | ________________ | __________

Notes / Non-conformances:
_______________________________________________________________________________________________

_______________________________________________________________________________________________

_______________________________________________________________________________________________

_______________________________________________________________________________________________

_______________________________________________________________________________________________

_______________________________________________________________________________________________

_______________________________________________________________________________________________

_______________________________________________________________________________________________

Serial #: ____________ | Final status: PASS / FAIL / CONDITIONAL | Date shipped: ___________

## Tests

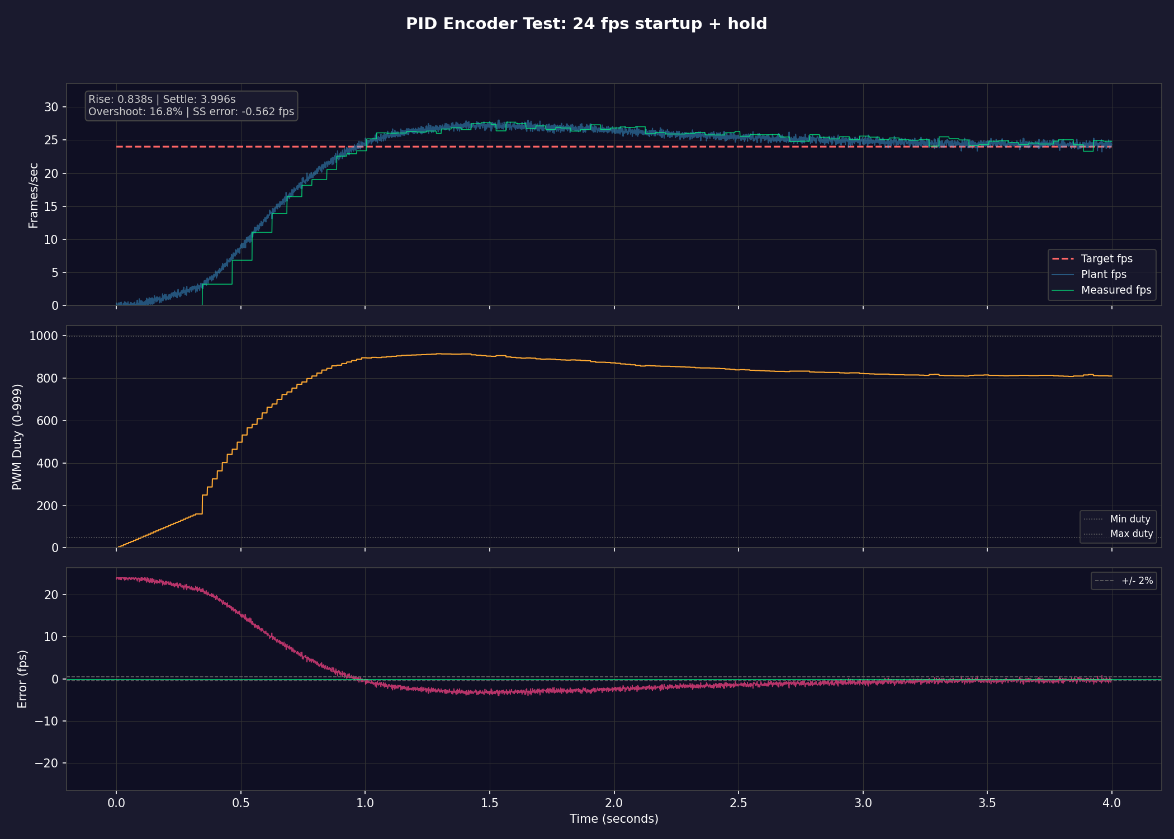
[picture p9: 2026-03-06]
pid_test_24fps.png

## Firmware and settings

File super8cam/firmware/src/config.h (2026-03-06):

/**
 * config.h — Super 8 Camera Firmware Configuration
 *
 * Single source of truth for all firmware constants.  Values derived from
 * super8cam/specs/master_specs.py.  Regenerate with build.py if specs change.
 *
 * Organisation:
 *   SYSTEM       Clock, tick, debug
 *   MOTOR / PID  Speed control tuning
 *   ENCODER      Input capture timing
 *   METERING     ADC, calibration LUT, exposure math
 *   BATTERY      Voltage monitoring
 *   CARTRIDGE    End-of-film detection
 *   UI           LEDs, debounce, galvanometer
 */

#ifndef CONFIG_H
#define CONFIG_H

#include <stdint.h>

/* =====================================================================
 * SYSTEM
 * ===================================================================== */

#define SYS_HSI_HZ              16000000U   /* HSI16 oscillator             */
#define SYS_TICK_HZ             1000U       /* SysTick rate (1 ms)          */
#define SYS_TICK_RELOAD         (SYS_HSI_HZ / SYS_TICK_HZ - 1U)  /* 15999  */

/* UART debug output (USART2 on PA9/PA10) */
#define UART_BAUDRATE           115200U
#define UART_DEBUG_INTERVAL_MS  500U        /* telemetry print rate         */

/* =====================================================================
 * FRAME RATES
 * ===================================================================== */

#define FPS_LOW                 18U
#define FPS_HIGH                24U

/* =====================================================================
 * MOTOR PWM  (TIM2 CH1)
 *
 * 16 MHz / (15+1) / (999+1) = 1 kHz PWM
 * ===================================================================== */

#define PWM_TIM_PRESCALER       15U
#define PWM_TIM_PERIOD          999U
#define PWM_DUTY_MIN            50U         /* minimum to overcome friction */
#define PWM_DUTY_MAX            999U        /* 100% duty                    */

/* =====================================================================
 * PID CONTROLLER
 *
 * Tuned for Mabuchi FF-130SH through 15:1 Delrin gearbox.
 * ===================================================================== */

#define PID_KP                  1.8f
#define PID_KI                  0.9f
#define PID_KD                  0.05f
#define PID_INTERVAL_MS         20U         /* PID update rate (50 Hz)      */
#define PID_I_CLAMP             400.0f      /* anti-windup: max |integral|  */
#define PID_D_FILTER_ALPHA      0.3f        /* derivative low-pass: 0=hold, 1=raw */
#define PID_DUTY_RATE_LIMIT     50U         /* max duty change per PID cycle */

/* =====================================================================
 * STARTUP / STOP RAMP
 * ===================================================================== */

#define RAMP_STEP               5U          /* duty increment per ramp tick */
#define RAMP_INTERVAL_MS        10U         /* ms between ramp steps        */
#define RAMP_TARGET_PCT         40U         /* open-loop target as % of max */

#define STOP_STEP               8U          /* duty decrement per stop tick  */
#define STOP_INTERVAL_MS        8U          /* ms between stop steps         */
#define STOP_TIMEOUT_MS         2000U       /* max time to wait for stop     */

/* =====================================================================
 * STALL DETECTION
 * ===================================================================== */

#define STALL_TIMEOUT_MS        200U        /* kill motor if no pulse       */
#define STALL_STARTUP_MULT      3U          /* extra patience during ramp   */

/* =====================================================================
 * ENCODER  (TIM21 CH1 input capture)
 *
 * 16 MHz / (15+1) = 1 MHz → 1 µs resolution.
 * At 24 fps: period ≈ 41 667 µs — fits 16-bit counter (65 535 max).
 * At 18 fps: period ≈ 55 556 µs — fits 16-bit counter.
 * ===================================================================== */

#define ENC_TIM_PRESCALER       15U
#define ENC_AVG_SIZE            4U          /* moving-average window         */

/* =====================================================================
 * ADC / METERING
 * ===================================================================== */

#define METER_ADC_CHANNEL       7U          /* PA7 = ADC_IN7                */
#define METER_SAMPLE_HZ         100U        /* ADC sampling rate            */
#define METER_FILTER_SIZE       16U         /* rolling-average depth        */
#define ADC_VREF_MV             3300U       /* VDDA reference               */
#define ADC_RESOLUTION          4096U       /* 12-bit ADC                   */

/* Calibration LUT: ADC millivolts → EV at ISO 100.
 * Populate from a known-light calibration session with BPW34 + TIA.
 * Must be monotonically increasing in mV. */
#define CAL_TABLE_SIZE          13

/* =====================================================================
 * GALVANOMETER NEEDLE  (TIM22 CH1)
 *
 * Same PWM rate as motor: 1 kHz for smooth needle movement.
 * ===================================================================== */
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

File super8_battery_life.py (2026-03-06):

#!/usr/bin/env python3
"""Super 8 Camera Battery Life Calculator

Models total system power draw, estimates runtime and cartridges per
battery set, and plots a voltage-sag derating curve showing how motor
speed degrades over the discharge cycle.

Power source: 4x AA cells in series (6V nominal).
"""

import numpy as np
import matplotlib
matplotlib.use("Agg")
import matplotlib.pyplot as plt


# ---------------------------------------------------------------------------
# Battery specifications
# ---------------------------------------------------------------------------
NUM_CELLS = 4

BATTERY_TYPES = {
    "Alkaline": {
        "capacity_mAh": 2800,       # at moderate drain (~200 mA)
        "v_fresh": 1.60,            # V per cell, fresh off shelf
        "v_nominal": 1.50,          # V per cell, nominal
        "v_cutoff": 1.00,           # V per cell, effective empty
        # Piecewise-linear discharge profile: (fraction_used, voltage_per_cell)
        # Approximates a typical alkaline AA curve at ~200 mA drain
        "discharge_curve": [
            (0.00, 1.60),
            (0.05, 1.50),
            (0.15, 1.45),
            (0.40, 1.30),
            (0.60, 1.20),
            (0.80, 1.10),
            (0.90, 1.05),
            (1.00, 1.00),
        ],
    },
    "NiMH": {
        "capacity_mAh": 2000,
        "v_fresh": 1.40,
        "v_nominal": 1.20,
        "v_cutoff": 1.00,
        # NiMH has a flatter discharge plateau
        "discharge_curve": [
            (0.00, 1.40),
            (0.05, 1.30),
            (0.10, 1.25),
            (0.70, 1.22),
            (0.85, 1.20),
            (0.90, 1.15),
            (0.95, 1.10),
            (1.00, 1.00),
        ],
    },
}


# ---------------------------------------------------------------------------
# Component current draws (mA)
# ---------------------------------------------------------------------------
COMPONENTS = {
    "DC motor (FF-130, loaded)":  200.0,
    "STM32L0 MCU (active)":        5.0,
    "Motor driver IC (quiescent)":  2.0,
    "Metering photodiode circuit":  1.0,
    "Voltage regulators (2x)":      0.1,   # 50 uA each
    "Viewfinder LED":              10.0,
}


# ---------------------------------------------------------------------------
# Camera parameters
# ---------------------------------------------------------------------------
FRAME_RATES = [18, 24]

# Cartridge run times (50 ft Super 8 cartridge)
CARTRIDGE_TIME = {18: 3.333, 24: 2.500}  # minutes

# Mabuchi FF-130 motor characteristics
MOTOR_RATED_RPM = 6600   # at rated voltage
MOTOR_RATED_V = 3.0      # rated voltage
MOTOR_NO_LOAD_RPM = 9600 # free-running RPM at rated voltage

# The motor driver uses PWM to regulate the motor to the target shaft RPM.
# Under load the motor needs a certain voltage to sustain the required RPM.
# The driver can deliver at most (V_pack - driver_drop) to the motor.
# When pack voltage sags below what the driver needs, it can no longer
# maintain the target RPM and the motor (and frame rate) slows down.
DRIVER_DROP_V = 0.3       # H-bridge / driver saturation drop (V)
MCU_REG_HEADROOM_V = 0.5  # LDO headroom for 3.3V MCU regulator

# Target motor voltages at each fps (derived from drivetrain gear ratios):
#   main_shaft_rpm = fps * 60
#   gear_ratio = MOTOR_RATED_RPM / main_shaft_rpm  (from drivetrain calc)
#   motor_rpm_needed = main_shaft_rpm * gear_ratio = fps * 60 * gear_ratio
#   But with load, motor draws current and speed drops from back-EMF.
#   V_motor = V_rated * (RPM_target / RPM_no_load_at_rated)  approximately
# For a loaded FF-130 at the required RPMs:
#   18 fps: shaft=1080 RPM, gear=6.11:1, motor=6600 RPM -> V~2.06V
#   24 fps: shaft=1440 RPM, gear=4.58:1, motor=6600 RPM -> V~2.06V
# Both need ~2.1V at the motor terminals (same motor RPM, different gearing).
# Under load the motor draws more current, increasing I*R losses in the
# windings, so we need somewhat more voltage.  Estimate ~2.5V under load.
MOTOR_V_NEEDED_LOADED = 2.5  # V needed at motor terminals under load


# ---------------------------------------------------------------------------
# Calculations
# ---------------------------------------------------------------------------

def total_system_current_mA():
    """Sum of all component draws at nominal voltage."""
    return sum(COMPONENTS.values())


def system_current_at_voltage(v_pack, v_nominal):
    """Estimate real system current accounting for constant-power motor load.

    The motor driver maintains target RPM via PWM.  As voltage drops, the
    driver increases duty cycle, drawing more current to deliver the same
    mechanical power.  P = V * I = const, so I increases as V decreases.

    Other components (MCU, LED, etc.) draw roughly constant current.
    """
    motor_nominal_mA = COMPONENTS["DC motor (FF-130, loaded)"]
    other_mA = sum(v for k, v in COMPONENTS.items()
                   if k != "DC motor (FF-130, loaded)")

    # Motor current scales inversely with voltage (constant power)
    # Clamp ratio to avoid unrealistic values at very low voltage
    v_ratio = max(v_pack / v_nominal, 0.5)
    motor_current = motor_nominal_mA / v_ratio

    return motor_current + other_mA


def runtime_minutes(capacity_mAh, current_mA):
    """Ideal runtime in minutes from capacity and current."""
    return (capacity_mAh / current_mA) * 60


def cartridges_per_set(runtime_min, fps):
    """Number of 50-ft cartridges that fit in the runtime."""
    return runtime_min / CARTRIDGE_TIME[fps]


def interpolate_discharge(curve, n_points=200):
    """Interpolate a discharge curve to n evenly-spaced points.

    Returns (fraction_used, voltage_per_cell) arrays.
    """
    fracs = [p[0] for p in curve]
    volts = [p[1] for p in curve]
    frac_interp = np.linspace(0, 1, n_points)
    volt_interp = np.interp(frac_interp, fracs, volts)
    return frac_interp, volt_interp


def motor_speed_fraction(pack_voltage):
    """Motor speed as fraction of target RPM given pack voltage.

    The motor driver regulates via PWM to maintain target RPM as long as the
    pack voltage is high enough.  Once V_pack drops below the minimum needed
    (motor voltage + driver drop), the driver saturates at 100% duty and motor
    speed becomes proportional to available voltage.

    Returns 1.0 when pack can sustain target, <1.0 when it cannot.
    """
    v_available = max(pack_voltage - DRIVER_DROP_V, 0)
    v_needed = MOTOR_V_NEEDED_LOADED

    if v_available >= v_needed:
        return 1.0
    else:
        return v_available / v_needed
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

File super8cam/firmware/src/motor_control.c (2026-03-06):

/**
 * motor_control.c — PID Closed-Loop DC Motor Speed Controller
 *
 * Drives the Mabuchi FF-130SH via TIM2 CH1 PWM.  Speed feedback from
 * the encoder module (TIM21 input capture, 4-sample average).
 *
 * Startup sequence:
 *   1. motor_start() → state = RAMP_UP, duty = PWM_DUTY_MIN
 *   2. Duty ramps at RAMP_STEP per RAMP_INTERVAL_MS toward 40% target
 *   3. On first encoder feedback → state = RUNNING, PID takes over
 *
 * PID features:
 *   - Anti-windup: integral clamped to ±PID_I_CLAMP
 *   - Derivative filter: first-order low-pass (alpha = PID_D_FILTER_ALPHA)
 *   - Rate limiting: duty change capped to ±PID_DUTY_RATE_LIMIT per cycle
 *
 * All constants from config.h; all pins from pinmap.h.
 *
 * Copyright (c) 2026 — released under MIT license.
 */

#include "motor_control.h"
#include "encoder.h"
#include "config.h"
#include "pinmap.h"
#include "stm32l0xx.h"

/* Global tick from main.c */
extern volatile uint32_t g_tick_ms;

/* =====================================================================
 * Internal state
 * ===================================================================== */

static motor_state_t mstate       = MOTOR_IDLE;
static uint16_t      current_duty = 0;
static float         measured_fps = 0.0f;

/* PID state */
static float pid_integral   = 0.0f;
static float pid_prev_error = 0.0f;
static float pid_d_filtered = 0.0f;

/* Timing */
static uint32_t next_pid_ms  = 0;
static uint32_t next_ramp_ms = 0;

/* =====================================================================
 * Low-level helpers
 * ===================================================================== */

/** Set PWM duty cycle (clamped to 0 .. PWM_DUTY_MAX). */
static void set_duty(uint16_t d)
{
    if (d > PWM_DUTY_MAX) d = PWM_DUTY_MAX;
    TIM2->CCR1   = d;
    current_duty = d;
}

/** Reset PID accumulator state. */
static void pid_reset(void)
{
    pid_integral   = 0.0f;
    pid_prev_error = 0.0f;
    pid_d_filtered = 0.0f;
}

/** Fault LED on PA3. */
static inline void fault_led(uint8_t on)
{
    if (on) PIN_LED_WARN_PORT->BSRR = (1U << PIN_LED_WARN_PIN);
    else    PIN_LED_WARN_PORT->BSRR = (1U << (PIN_LED_WARN_PIN + 16));
}

/* =====================================================================
 * PID controller
 *
 * Input:  target fps, measured fps
 * Output: new PWM duty value
 *
 * Anti-windup:    integral clamped to ±PID_I_CLAMP
 * Derivative:     low-pass filtered (alpha blend with previous)
 * Rate limiting:  output change capped to ±PID_DUTY_RATE_LIMIT
 * ===================================================================== */

static uint16_t pid_compute(float target, float actual)
{
    float error = target - actual;
    float dt    = (float)PID_INTERVAL_MS / 1000.0f;

    /* Proportional */
    float p_term = PID_KP * error;

    /* Integral with anti-windup */
    pid_integral += PID_KI * error * dt;
    if (pid_integral >  PID_I_CLAMP) pid_integral =  PID_I_CLAMP;
    if (pid_integral < -PID_I_CLAMP) pid_integral = -PID_I_CLAMP;

    /* Derivative with low-pass filter */
    float d_raw = PID_KD * (error - pid_prev_error) / dt;
    pid_d_filtered = PID_D_FILTER_ALPHA * d_raw
                   + (1.0f - PID_D_FILTER_ALPHA) * pid_d_filtered;
    pid_prev_error = error;

    /* Sum PID terms */
    float output = (float)current_duty + p_term + pid_integral + pid_d_filtered;

    /* Clamp to valid duty range */
    if (output < (float)PWM_DUTY_MIN) output = (float)PWM_DUTY_MIN;
    if (output > (float)PWM_DUTY_MAX) output = (float)PWM_DUTY_MAX;

    /* Rate limiting: restrict change per PID cycle */
    uint16_t new_duty = (uint16_t)output;
    if (new_duty > current_duty + PID_DUTY_RATE_LIMIT)
        new_duty = current_duty + PID_DUTY_RATE_LIMIT;
    else if (current_duty > PID_DUTY_RATE_LIMIT &&
             new_duty < current_duty - PID_DUTY_RATE_LIMIT)
        new_duty = current_duty - PID_DUTY_RATE_LIMIT;

    return new_duty;
}

/* =====================================================================
 * Hardware Init
 * ===================================================================== */

void motor_init(void)
{
    /* Enable clocks */
    RCC->IOPENR  |= RCC_IOPENR_GPIOAEN;
    RCC->APB1ENR |= RCC_APB1ENR_TIM2EN;

    /* PA0: TIM2_CH1 alternate function (AF2), push-pull */
    PIN_PWM_MOTOR_PORT->MODER =
        (PIN_PWM_MOTOR_PORT->MODER & ~(3U << (PIN_PWM_MOTOR_PIN * 2)))
        | (2U << (PIN_PWM_MOTOR_PIN * 2));
    PIN_PWM_MOTOR_PORT->AFR[0] =
        (PIN_PWM_MOTOR_PORT->AFR[0] & ~(0xFU << (PIN_PWM_MOTOR_PIN * 4)))
        | (PIN_PWM_MOTOR_AF << (PIN_PWM_MOTOR_PIN * 4));

    /* PA3: fault LED — output push-pull */
    PIN_LED_WARN_PORT->MODER =
        (PIN_LED_WARN_PORT->MODER & ~(3U << (PIN_LED_WARN_PIN * 2)))
        | (1U << (PIN_LED_WARN_PIN * 2));
    fault_led(0);

    /* TIM2: PWM mode 1 on CH1
     * 16 MHz / (15+1) / (999+1) = 1 kHz */
    TIM2->PSC  = PWM_TIM_PRESCALER;
    TIM2->ARR  = PWM_TIM_PERIOD;
    TIM2->CCR1 = 0;

    TIM2->CCMR1 = (TIM2->CCMR1 & ~0x7FU)
                 | TIM_CCMR1_OC1M_2 | TIM_CCMR1_OC1M_1
                 | TIM_CCMR1_OC1PE;

    TIM2->CCER |= TIM_CCER_CC1E;
    TIM2->CR1  |= TIM_CR1_ARPE;
    TIM2->EGR   = TIM_EGR_UG;
    TIM2->CR1  |= TIM_CR1_CEN;

    /* Init encoder subsystem */
    encoder_init();

    /* Zero motor state */
    mstate       = MOTOR_IDLE;
    current_duty = 0;
    measured_fps = 0.0f;
    pid_reset();
}

/* =====================================================================
 * State Machine Update — call from superloop every tick
 * ===================================================================== */
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

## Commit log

2026-03-06 Add Super 8 camera drivetrain calculator
    Calculates motor RPM, gear reduction ratios, claw timing, and
    dwell periods for 18/24 fps using Mabuchi FF-130 motor specs.
    Flags timing violations when pulldown can't complete in the
    available shutter-closed window.
    https://claude.ai/code/session_01NTtBu3U4VJGD4RjXh61kQc
2026-03-06 Add pulldown claw mechanism model with motion profiles
    Scotch-yoke model computing claw position, velocity, and acceleration
    over one shaft revolution at 18/24 fps. Checks inertial + friction
    forces against Kodak perforation pull strength (1.5N) and calculates
    bending stress on the hardened steel claw tip. Generates matplotlib
    plots of all three motion profiles.
    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
2026-03-06 Add battery life calculator with voltage-sag derating model
    Calculates total system current (218 mA across 6 components), runtime
    with integrated constant-power discharge model, and cartridges per
    battery set for alkaline and NiMH cells at 18/24 fps. Plots pack
    voltage and motor speed vs cartridges shot with regulation thresholds.
    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
    [super8_battery_life.py]
2026-03-06 Add exposure calculator with EV table and metering circuit analysis
    Computes effective shutter speeds (1/36s at 18fps, 1/48s at 24fps),
    f-stop lookup for 4 film stocks across EV 5-15, and BPW34 photodiode
    metering circuit design: photocurrent range, transimpedance gain, and
    ADC resolution. Flags low-light ADC resolution limits.
    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
2026-03-06 Add parametric CadQuery film gate model with STEP/STL export
    Models a Super 8 film gate plate (25x18x3mm) with Kodak-spec aperture
    (5.79x4.01mm), film channel, registration pin hole at 4.234mm pitch,
    pressure-plate lip, and M2 mounting holes. All dimensions parameterized.
    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
    [film_gate.step, film_gate.stl]
2026-03-06 Add parametric CadQuery rotary shutter disc model
    Half-circle shutter with adjustable opening angle (default 180°),
    shaft hole with keyway, balance holes on the solid sector, and an
    optical sensor flag notch. Exports STEP and STL.
    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
    [shutter_disc.step, shutter_disc.stl]
2026-03-06 Add parametric CadQuery camera body shell for layout purposes
    Hollow shell (150x90x55mm, 3mm walls) with C-mount lens opening,
    cartridge loading door cutout, 4xAA battery pocket, 1/4-20 tripod
    boss, and 4x M2 PCB standoff posts. All dimensions parameterized.
    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
    [camera_body.step, camera_body.stl]
2026-03-06 Add closed-loop PID motor control firmware for Super 8 film transport
    Bare-register STM32L0 firmware: TIM2 CH1 PWM drive, TIM21 CH1 input
    capture for optical encoder (1 pulse/frame). PID loop at 50 Hz,
    18/24 fps toggle switch, soft start/stop ramps, 200 ms stall timeout.
    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
    [motor_control.c]
2026-03-06 Add light metering firmware: photodiode ADC → EV → f-stop → galvanometer
    BPW34 photodiode read via ADC at 100 Hz with 16-sample rolling average,
    calibration LUT interpolation to EV, f-stop calculation for selected
    ASA (50/100/200/500) and shutter speed (1/36s or 1/48s). Drives a
    galvanometer needle via PWM and green/red exposure status LEDs.
    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
2026-03-06 Add main firmware integrating motor, metering, and system management
    State machine (IDLE → RUNNING → STOPPING → CARTRIDGE_EMPTY → IDLE)
    with EXTI-driven trigger/FPS switch, frame counting via encoder
    callback, cartridge-end detection (5 missed frames), VBAT battery
    monitoring with low-voltage warning, and unified SysTick. Includes
    Makefile for ARM GCC and platformio.ini for PlatformIO builds.
    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
    [main.c]
2026-03-06 Add KiCad schematic/netlist generator and BOM for control board
    Python script generates .kicad_sch, .net, and BOM CSV for 39 components:
    STM32L031K6, DRV8837, BPW34+MCP6001 TIA, dual AMS1117 regulators,
    SI2301 reverse-polarity protection, polyfuse, connectors, and passives.
    All nets defined matching the firmware pin allocation.
    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
    [super8_camera.kicad_sch, super8_camera_bom.csv]
2026-03-06 Add BOM cost analyzer with tiered pricing and alternative suggestions
    Reads BOM CSV, looks up realistic LCSC/DigiKey 2025 pricing at qty 1/25/100,
    flags parts >20% of total cost, suggests pin-compatible cheaper alternatives
    (STM32L011, MX1508, HT7x33/50, AO3401A, BPW34S). Prototype BOM: $10.42,
    optimized at 100pc: $3.46.
    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
2026-03-06 Add film transport mechanism simulation with matplotlib animation
    Models the 4-phase claw/shutter cycle: expose (0-180deg), engage
    (180-230deg), pulldown 4.234mm (230-330deg), retract (330-360deg).
    Side view + claw detail + timing diagram. Generates static previews
    in headless mode, .mp4 with --save flag. Supports 18 and 24 fps.
    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
2026-03-06 Add PID controller simulation with synthetic encoder test bench
    Software model of firmware PID (Kp=1.8, Ki=0.9, Kd=0.05) with motor
    plant, encoder jitter (+/-2%), missed pulses (1/200), and startup ramp.
    Tests 18fps, 24fps, and mid-run speed switch. Plots fps/duty/error
    time series with quantitative metrics (rise time, overshoot, settling).
    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
2026-03-06 Add production build checklist PDF generator (101 items, 10 sections)
    Reportlab-based PDF with: incoming inspection (31 parts with acceptance
    criteria), 4 sub-assembly procedures (film gate, shutter, motor, PCB),
    16-step final assembly with torque specs and alignment checks,
    metering + motor calibration, 8 QC tests, and sign-off block.
    Checkboxes, serial number, technician fields throughout.
    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
2026-03-06 Add super8cam Python package with master_specs single source of truth
    Complete project restructure into a proper Python package with:
    - specs/master_specs.py: all dimensions, tolerances, materials, and constants
    - parts/: 22 CadQuery parametric part modules (film gate, shutter, body, etc.)
    - assemblies/: 7 CadQuery assembly modules (full camera, drivetrain, etc.)
    - analysis/: kinematics, timing validation, tolerance stackup, thermal
    - manufacturing/: BOM generator, inspection checklist, GD&T standards
    - firmware/src/: refactored STM32L0 C firmware with centralized config
    - build.py: master build orchestrator with --specs/--parts-only/--analysis-only
    Every file imports from master_specs —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
    [build.py, cartridge_receiver.py]
2026-03-06 Rebuild film gate and pressure plate with full precision features
    Film gate (brass C360, 24×20×4mm):
    - Tapered aperture (0.2mm wider on lens side) with 0.05mm chamfer
    - Film channel 8.2mm×0.20mm deep with polished contact rails (1.5mm×0.15mm)
    - Perforation clearance slot and claw access through-slot
    - Registration pin hole 0.82mm H7 at one perf pitch below center
    - 4× M2 threaded holes on 20×16mm pattern + 2× dowel pin holes
    - get_film_plane_origin() returns the camera's master reference point
    Pressure plate (301SS, 22×18×0.3mm):
    - Two raised contact pads (3×12mm) aligned with gate rails
    - Integral leaf spring cantilevers providing 0.5N total force
    - Spring deflection calculated f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
2026-03-06 Rebuild claw mechanism with eccentric cam system and full kinematics analysis
    parts/cam_follower.py — Complete cam/follower system:
    - Face cam disc (16mm OD, 3mm thick) with groove profile encoding
    modified trapezoidal (1/4-1/2-1/4) pulldown motion for minimal jerk
    - Secondary eccentric (10mm, 0.8mm offset, 90° phase) for engage/retract
    - Follower pin, connecting link, guide rail pins, e-clip placeholders
    - Parametric cam_profile_full() generates claw (x,y) at any shaft angle
    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
2026-03-06 Rebuild main shaft, shutter disc, and shutter assembly with full validation
    parts/main_shaft.py — Stepped shaft with 6 sections:
    - Gear end (3mm×8mm, 0.6mm keyway), bearing seats (4mm×4mm, h6),
    cam section (4mm×6mm, 1mm keyway), shutter seat (4mm×3mm, keyed),
    encoder end (3mm×4mm, M3 thread at tip)
    - 0.3mm×45° chamfers at all diameter transitions
    - get_section_positions() provides Z coords for assembly
    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
2026-03-06 Rebuild camera body shell, plates, doors, and trigger mechanism
    - Body left half: 2.5mm wall aluminum shell with integrated bearing bore,
    gearbox M3 bosses, motor pocket, PCB standoffs (4x M2, 6mm), 5x M2.5
    split-line screw bosses, lens mount opening, tripod boss half
    - Body right half: cartridge receiver pocket (68x63mm), loading door opening
    with 2mm light trap ledge, trigger button hole + mechanism mount, bearing
    housing, guide roller mounts, strap lug, M2.5 clearance holes with
    counterbores
    - Top plate: ISO 518 cold shoe (18mm slot with spring contact recess),
    viewfinder M2 mount holes (30mm spacing, 5mm left offset), strap lug,
    4x M2.5 countersunk mounting
    - Bottom plate: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
2026-03-06 Add analysis, firmware, manufacturing, and build pipeline
    - Complete 7-phase build pipeline (build.py): specs, validation, analysis,
    parts export, assemblies export, interference detection, manufacturing outputs
    - Full camera assembly with 14-pair interference detection and shutter sweep
    - Timing validation (7 rules), tolerance stack-ups, thermal analysis, kinematics
    - STM32L031K6 bare-metal CMSIS firmware: PID motor control, optical encoder,
    light metering, state machine (also targets Arduino Nano for prototyping)
    - Manufacturing outputs: 48-item BOM with cost rollup, 7 engineering drawing
    PDFs with GD&T, 111-item production checklist
    - Project README with specs, build instructions, a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
    [build.py, config.h, encoder.c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]
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2026-03-08 Fix cam/timing system: insufficient dwell between claw retract and shutter open
    Restructure cam profile to eliminate phase wrapping across 0° and ensure
    film is fully stationary with registration pin engaged before exposure.
    New phase map (no wrap-around):
    0°-180° exposure, 185°-190° engage, 190°-330° pulldown,
    330°-335° retract, 335°-350° return, 350°-360° dwell
    - Replace modified trapezoidal profile with cycloidal (modified sine)
    motion for zero velocity at stroke endpoints and finite jerk
    - Increase dwell before shutter open from 5° to 10°
    - Path now closes exactly (position at 0° = position at 360°)
    - Film velocity confirmed 0 mm/s at shutter open for both 18/24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
2026-03-08 Fix 9 interference detection failures in assembly datum positions
    Resolve all part-to-part interferences by adjusting datum positions in
    full_camera.py (7 fixes) and enlarging geometry in body_right.py and
    lens_mount.py (2 fixes):
    - Shutter disc vs film gate: +0.8mm axial separation
    - Claw vs film gate: move behind gate rear face (enters through perf slot)
    - Motor mount vs body left: shift 3mm inward (flush with gearbox)
    - PCB vs body left: shift 2mm toward center
    - Cartridge receiver vs body right: enlarge pocket +2mm each side
    - Shutter disc vs pressure plate: offset pressure plate 0.5mm further
    - Pulldown cam vs film gate: shift cam 8mm further from gate
    - Viewfinder vs top plate: lower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
2026-03-08 Fix interference detection: apply assembly Location transforms to parts
    The interference checker was comparing all parts at the origin (0,0,0)
    instead of at their actual assembly positions. `_iter_assembly_parts`
    extracted `child.obj` (the raw, untransformed shape) but ignored
    `child.loc` (the Location transform from `assy.add(..., loc=...)`).
    This meant that modifying datum position variables (SHAFT_Z, MOTOR_X,
    etc.) had zero effect on interference results — the volumes were
    identical to 4 decimal places across every build.
    Fix: apply `solid.moved(loc)` to each part before boolean intersection.
    Add VERIFY_INTERFERENCE.py for quick local validation with CadQuery.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
2026-03-08 Fix 4 remaining container-too-small interferences
    1. gearbox_housing: enlarge internal cavity by 2mm per axis so
    stage2_gear clears housing walls (was 83 mm³)
    2. body_left: add PCB board clearance pocket (+3mm per axis) to
    prevent pcb_board clipping through shell wall (was 71 mm³)
    3. body_right: enlarge cartridge receiver pocket by 3mm per axis
    so receiver fits inside body half (was 427 mm³)
    4. top_plate: add viewfinder tube through-cut with 5mm clearance
    margin where tube passes through plate (was 35 mm³)
2026-03-08 Enlarge cavities more aggressively to clear 3 remaining interferences
    1. gearbox_housing: inner cavity now +5mm per axis (was +2mm),
    stage2_gear had 39.6 mm³ remaining
    2. body_left: PCB pocket now +6mm per axis (was +3mm),
    pcb_board had 23.2 mm³ remaining
    3. body_right: cartridge pocket now +10mm per axis (was +3mm),
    receiver had 419.6 mm³ remaining — previous fix barely helped
2026-03-08 Fix all interference failures: body half positioning and pocket ordering
    Root causes found and fixed:
    - Body halves had double-translation: build() already positions geometry
    at X=[0,±HALF_L], but assembly added ±body_length/4 offset, shifting
    internal pockets 37mm from where parts actually sit
    - Gearbox housing inner cavity exceeded outer dimensions (previous +5mm
    enlargement consumed all solid), fixed by enlarging outer instead
    - Gearbox housing not centered on gear train — shifted to midpoint
    - Motor mount overlapped body_left bearing boss, shifted +6mm right
    - PCB pocket and cartridge pocket cuts were applied BEFORE union ops
    (screw bosses, bearing bosses) which added materia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
2026-03-08 Shrink body to 135x80x48mm with lofted shell profiles
    Redesign camera body from 148x88x52mm to 135x80x48mm (~Canon 514XL size)
    with multi-section lofted shells replacing box+wedge approach. All 14
    interference pairs pass, shutter clearance verified.
    - master_specs: body dims, grip 22x22x50, vents 4x10mm, gearbox_gear_clearance
    - body_left/right: 4-station YZ loft with 3-tier fallback (ruled/smooth/box)
    - gearbox_housing: use gear OD instead of PCD, parameterized clearance
    - full_camera: CART_X shifted left for compact envelope
    - bottom_plate: grip cutout clamped to plate edge
    - layout_diagnostic.py: new packing analysis script
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2026-03-08 Fix shell integration: ray-based scaling, convex hull containment
    Replace hardcoded body dimensions with CadQuery assembly-measured
    internals bounding box. Use ray-based effective interior measurement
    to account for camera mesh shape (fill ratios 0.5-0.7). Align shell
    centroid to internals centroid. Generate convex hull for reliable
    containment, with iterative expansion until all 26 target BB sample
    points are inside. Skip hollowing for watertight hulls to preserve
    signed distance checks. verify_shell_fit.py now passes 22/22 parts.
2026-03-08 Add interactive web explorer with 3D model viewers, build guide, and repair manual
    React + Vite + Three.js webapp at webapp/ with 8 pages:
    - Home: full 3D assembly viewer with all 27 parts, key stats, module grid
    - Modules: 7 field-swappable module cards with detail pages showing per-module 3D views, parts tables, connector pinouts, and repair procedures
    - Build Guide: 10-step assembly sequence with progressive 3D viewer that highlights newly added parts at each step, keyboard navigation
    - Repair Guide: symptom-based diagnosis with 3D views highlighting affected parts in red
    - Specs: all specifications, interactive cam timing SVG diagram, validation results, tolerance stack-up visualization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
